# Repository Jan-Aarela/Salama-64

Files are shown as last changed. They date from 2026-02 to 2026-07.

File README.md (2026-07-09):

<!-- vim: ft=markdown nospell
-->
<i>

# Selkäsalama-64
Möykkäwaunujen proto salaman teon aikana huomasin, että salaman koko oli pikkasen pienempi mitä kuvittelin. Täysin toimiva siitähän tuli ja varsin hieno vaikka nopeasti tekasin sen.

Kaytin protoversiota yövalona kotona :D ja iski idea. Mitä jos, tästä tekisi selkäsalaman.  
[Niinkuin ysärillä...](https://github.com/Elektroniikkakerho/Archived-projects/tree/master/salama)  KiCadi tulille vaan ja lopputulos alla:

## Kuvia härpäkkeestä
|Homma in action|Etupuoli|Takapuoli| Takapuoli Kuorilla|
|---|---|---|---|
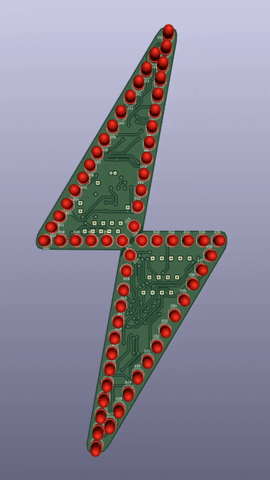
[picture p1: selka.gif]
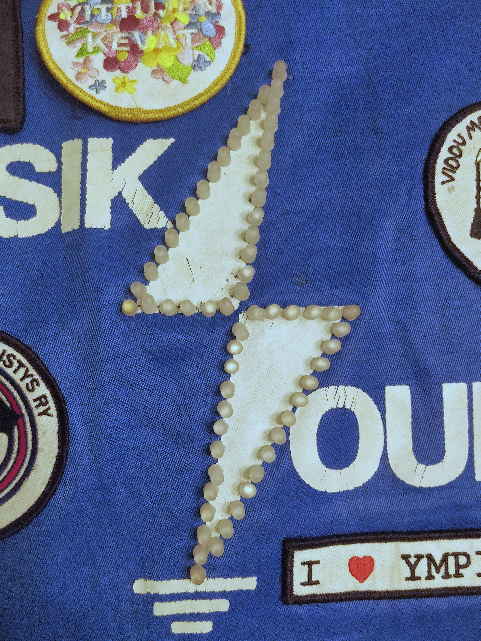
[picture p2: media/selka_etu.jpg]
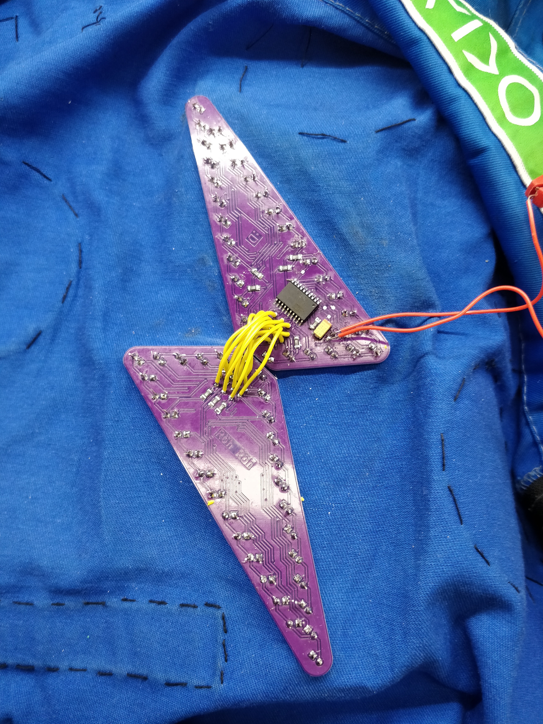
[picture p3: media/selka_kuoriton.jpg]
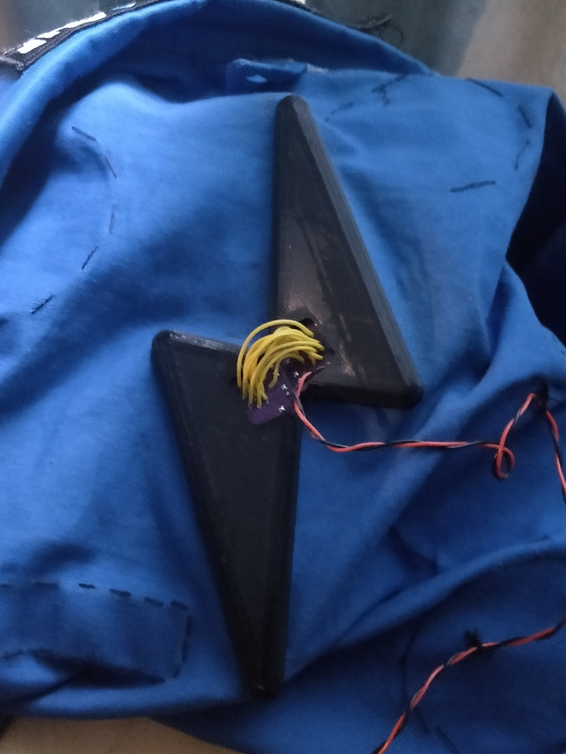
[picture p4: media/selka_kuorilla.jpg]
| | |  | 

## Skema
Homma toimii siten, että virtapankista tulee 5V ja menee suoraan piiriin. Konkka tasoittaa virran ja vastus toimii kuormana, mikäli virtapankki sammuu liian vähäistä virrankulutuksesta. Toinen ja energia tehokkaampi vaihtoehto on käyttää virtapankki kikkaa, eli ajoittain piikittää virran kulutusta ohjaamalla transistorin avulla vastusta.

Ledit on jaettu puolin kahteen eri charlieplexiin. (7^2-7 (-10) viritelmällä).  
Miksei kaikkia ledejä yhteen pleksiin? No siksi koska jos yhteen pleksiin laittaa kaikki ledit niin duty cycle olisi ~1.5%, joka on aika pieni. Kahdella pleksillä sen saa ~3%, jolloin ledit ovat kirkkaampia.

Napin tai liukukytkimen voi halutessa laittaa SW1 kohtaan johdoilla ja laittaa itse napin/liukukytkimen haalareihin, esim. kaulapantaan tai mikälie sen oikea nimi onkaan.



## Osaluettelo
| KPL | MITÄ | HUOM | 
|:---:|:--- |:--- |
|  1  | ATtiny 861A SOIC | Vähintään: Flash 4KB -  SRAM 256B |
|  64 | 5mm DIP LED | Tekijällä XL-502UBC ledit  |
|  14  | 27 Ohm 1206 | < 20ma per IO pin |
|  1  | 10 uF tant. 2312 SMD | Virtalähteen virran tasoitusta varten |
|  8  | Johdon pätkiä | Levyjen yhdistämiseen AWG 22-24 |
| 1 | Virtakaapelipari | Esim. USB |
| 1 | 6 pinninen rima | THT vaaka versio |

| Muuta?  |
|:---|
| Fläshäykseen Arduino ja 6 pinninen rima |
| PETG Filamettia kuorien tulostamiseen|
| (Optinal) Lisävastus mikäli salama sammuu|
| (Optinal) 2kpl 1206 100 nF keraamisia konkkia  |
| (Optinal) Nappi/Liukukytkin halutessa ja siihen johdot|

## Piirilevyt

Mikäli kerholla ei ole levyjä tähän projektiin, voit yrittää tehdä levyn esimerkiksi jyrsimällä tai etsaamalla. Tracien paksuudet ovat 0.4mm kestävyyden/tuotannon tolaranssin takia. Projektiin käy esimerkiksi 2-puoleinen 1oz 1.6mm PCB. Jos teet paksummasta levystä piirilevyt, joudut muokkaamaan kuorien mitat, jotta levyt mahtuvat niihin. 

Läpivientien kanssa joutuu painimaan sillä jyrsimisen/perus etsauksen jälkeen ne ei ilmesty itsestään vaan ne joutuu manuaalisesti tehdä ne. Yks tapa on käyttää läpivientiniittejä ja pressiä. Pressin jälkeen kannattaa ehdottamasti juottaa niitit traceihin, että varmasti toimivat. Jos niitit eivät mahdu reikiin, täytyy vaihtaa vioiden ja ledien reikien koot kicadillä. Tarkista, että niittien läpi mahtuu komponentit. Voi olla, että reikiä pitää kasvattaa...

## LEDIT
Tähän kannatta käyttää hyvin kirkkaita ledejä esim.  10000 mcd tai kirkkaammat,   
koska yhden ledin duty cycle on sen 1/32 ajasta eli ~ 3%.

Testaa ledin kirkkaus virtalähteellä.
Asetukset: square, 2.5V offset, 2.5V amplitude ja 3% duty cycle.

**Jos ledejä ei ole diffusoitu, niin ehdottamasti diffusoi ne.**  
Muuten selkäsalamasta tulee saatananmoinen valokeila ja sivusta katsottuna näyttää himmeältä.  

Hidas, mutta puhtaamman jäljen saat kun hiot jokaisen ledin 400-600 grid vesihiomapaperilla.

Toinen ja huomattavasti nopeampi tapa on käyttää hiekkapuhallinta. 
Eli laita kaikki ledit reikälevyyn ja teippaa ledien jalat.
Samaan tyliin kuin konkat tulee rullana. Ja ei muutakun hiekkapuhaltimella ammuskelemaan.
Voit puhdistaa ledit hiekasta laittamalla ledit astiaan jossa on nestettä (vesi/ipa) ja astian ultraäänipuhdistimeen.

## Kasausohjeet
Projekti aika pitkälti noudattaa possusalaman ohjeita.

 1. Juota siis piiri, konkka, 14 vastusta ja piikkirima.  
    Piikkirimasta trimmataan 4 sisimmäistä jalkaa, että se asettuisi lättänä.

2. Seuraavaksi laitetaan piirilevyt kiinni haalareihin.  
    Katko ledien jalat teräviksi ja yritä kohdistaa levy paikalleen.  
    Tässä kannattaa laittaa ledit niin, että haalarin salaman ääriviivat kulkee ledien keskellä.  
    Ledit mahdollisman hyvin kiinni piirilevyä vasten, näyttää suoremmalta.  
    Ja kannattaa jättää pieni rako piirilevyjen välille,  ettei hankaudu.  
    Tee sama toiselle piirilevylle. 

3. Sitten voit juottaa hyppyjohdot levylle, jossa on piiri.  
    Kannattaa juottaa hyvin ja niin että johdon muovi on mahdollisimman lähellä levyä.  
    Katko juottamisen jälkeen etupuolelta töpröttävät johdot pätkät.

4. Sittenkun kummatkin levyt ovat haalareissa kiinni, yhdistä levyt hyppykaapelilla.  
    Kaapelit menee järjestyksessä. Kanattaa olla vähän löysää, että koko härpäke pystyy taittumaan.

5. Kiinnitä Ardu piikkirimaan kiinni ja siirrä koodi levylle käyttäen AVR-ISP.  
    Ohjeet alempana.

6.  Jos kaikki toimii, juota seuraavaksi virtakaapeli ja tarvittaessa kuormavastus mikäli virtapankki lopettaa virranannon (virtasyöppö esto). Esim. 110 Ohm tai 169 Ohm...

7. Kuoret saa tulostettua FabLabilla ja mielellään kannattaa käyttää PETG. Tämä taipuu hyvin eikä halkea yhtä herkästi verrattuna esim. ABS muoviin. Tulostuksen jälkeen pitää putsata kuorien klipsien/kielien supportit pois. Esim varovasti veitsellä. Voit testata, että mahtuuko levy siihen, jos laitat 1.6mm levyn pätkän klipsin ja reunan (jossa piirilevyt istuu) väliin.

    Jos olet tehnyt piirilevyt paksummasta levystä, pitää muokata kuorien mittoja joko muokkaamalla STL tai blender projekti tiedostoa. 

8. Kuoret sopivat kummallekin piirilevylle.  
    Kolvilla voit tehdä master levyn kuoren reunalle reiän virtakaapelille.

    Kannattaa laittaa kuoret kiinni siten, että laitat ensin terävän kulman ensin kiinni ja siitä sitten siirry ylöspäin. Venytä kuorta ulospäin paina kiinni.

    Juuh, eikait siinä. Nyt **JÖÖTI** "possu" selässä  👌

## Koodi

```bash
# Siirry koodi kansioon
cd src/

# Koodin kääntäminen
avr-gcc -mmcu=attiny861 main.c kuviot.c vilkutus_charlie.c -I./ -Os -ffunction-sections -fdata-sections -Wl,--gc-sections -DF_CPU=8000000U

# Fuse asetukset
avrdude -c avrisp -p t861 -P /dev/ttyUSB0 -b 19200 -U lfuse:w:0xe2:m -U hfuse:w:0xdf:m

# Koodin siirto levylle
avrdude -c avrisp -p t861 -P /dev/ttyUSB0 -b 19200 -U flash:w:a.out

# Testaukseen voit käyttää yhtä komento riviä yhdistämällä koodin käännös ja siirto komennot (bash:)
avr-gcc -mmcu=attiny861 main.c kuviot.c vilkutus_charlie.c -I./ -Os -ffunction-sections -fdata-sections -Wl,--gc-sections -DF_CPU=8000000U && sudo avrdude -c avrisp -p t861 -P /dev/ttyUSB0 -b 19200 -U flash:w:a.out
```

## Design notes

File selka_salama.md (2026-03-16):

<!-- vim: ft=markdown nospell
-->
<i>

# Selkäsalama-64
Möykkäwaunujen proto salaman teon aikana huomasin, että salaman koko oli pikkasen pienempi mitä kuvittelin. Täysin toimiva siitähän tuli ja varsin hieno vaikka nopeasti tekasin sen.

Ihailin sitä tunteja ja mieleeni tuli yhtäkkiä idea. Mitä jos, tästä tekisi selkäsalaman. [Niinkuin ysärillä...](https://github.com/Elektroniikkakerho/Archived-projects/tree/master/salama)  
KiCadi tulille vaan ja lopputulos alla:

## Kuvia härpäkkeestä
|Demo|Etupuoli|Takapuoli Kuoriton| Takapuoli Kuorilla|
|---|---|---|---|
| | |  | 

## Skema
Koska selkäsalama koostuu kahdesta eri piirilevystä, skemaan on lisätty hyppykaapelit, jotka yhdistävät ledien multiplexauksen. esim. J13 --> J14.

Koska levy on niin täynnä traceja, enkä jaksunut vaivata, varsinaista piikkirimaa ohjelmoinille en laittanut. Levyssä on 4 pientä testi pädiä (lähellä piiriä), joihin juotetaan ohjelmointi kaapelit (RESET, SCK, MOSI JA MISO). Ohjelmoinnin aikana, voit käyttää kuormavastuksen pädejä (GND ja 5V).

Skemassa on cyaanin värisiä viivoja, jotka tarkoittavan piirin olevan alemmassa piirilevyssä.



## Osaluettelo
| KPL | MITÄ | HUOM | 
|:---:|:--- |:--- |
|  1  | ATtiny 861A SOIC | **U/SU** malli ainakin toimii  |
|  64 | 5mm DIP LED | Tekijällä XL-502UBC ledit  |
|  8  | 110Ohm 1206 | < 20ma per IO pin |
|  1  | 10uF tant. SMD | Virtalähteen virran tasoitusta varten |

| Muuta?  |
|:---|
| Joku kaapeli virransyöttä varten |
| Fläshäykseen Arduino ja 6 pinninen rima |
| Johdon pätkiä levyjen yhdistämiseen |
| PETG Filamettia kuorien tulostamiseen|
| Lisävastus mikäli salama sammuu|

## Piirilevyt
Mikäli kerholla ei ole levyjä tähän projektiin, voit yrittää tehdä levyn esimerkiksi jyrsimällä tai etsaamalla. Tracien paksuudet ovat 0.4mm kestävyyden/tuotannon tolaranssin takia. Projektiin käy esimerkiksi 2-puoleinen 1oz 1.6mm PCB. Jos teet paksummasta levystä piirilevyt, joudut muokkaamaan kuorien mitat, jotta levyt mahtuvat niihin. 

Läpivientien kanssa joutuu painimaan sillä jyrsimisen/etsauksen jälkeen ne ei ilmesty itsestään vaan ne joutuu manuaalisesti tehdä ne. Yks tapa on käyttää läpivientiniittejä ja pressiä. Pressin jälkeen kannattaa ehdottamasti juottaa niitit traceihin, että varmasti toimivat. Jos niitit eivät mahdu reikiin, täytyy vaihtaa vioiden ja ledien reikien koot kicadillä. 

## LEDIT
Tähän kannatta käyttää hyvin kirkkaita ledejä ~ 10000 mcd, sillä yhden ledin duty cycle on sen 1/64 ajasta eli ~ 1.5%. Tai tuplasti riippuen mitä koodin hedari tiedostoa käytät.

Testaa diffusoitu ledi virtalähteellä.  
Asetukset: square, 1.6V offset, 3.2V amplitude ja 1.5% tai 3% duty cycle.

Jos omasta mielestä sopivan kirkkaat ledit, ei muutakun kasamaan...

## Kasausohjeet
Projekti aika pitkälti noudattaa possusalaman ohjeita.

 1. Juota siis piiri, konkka ja 8 vastusta. Jätä konkan vierestä vastus juottamatta.  
    Se on kuormavastukselle varattu paikka ja käytetään myös ohjelmoinnissa.

2. Sitten voit juottaa hyppyjohdot levylle, jossa on piiri.  
    Kannattaa juottaa hyvin ja niin että johdon muovi on mahdollisimman lähellä levyä.  
    Katko juottamisen jälkeen etupuolelta töpröttävät johdot pätkät.

3. Seuraavaksi laitetaan piirilevyt kiinni haalareihin.  
    Katko ledien jalat teräviksi ja yritä kohdistaa levy paikalleen.  
    Tässä kannattaa laittaa ledit niin, että haalarin salaman ääriviivat kulkee ledien keskellä.  
    Suosittelen laittamaan ledit mahdollisman hyvin kiinni piirilevyä vasten, näyttää suoremmalta.  
    Ja kannattaa jättää pieni rako piirilevyjen välille,  ettei hankaudu.  
    Tee sama toiselle piirilevylle. 

    **Jos ledejä ei ole diffusoitu, niin ehdottamasti diffusoi ne.**  
    Muuten selkäsalamasta tulee saatananmoinen valokeila ja sivusta katsottuna näyttää himmeältä.  

    Hidas, mutta puhtaamman jäljen saat kun hiot jokaisen ledin 400-600 grid vesihiomapaperilla.  
    Toinen ja huomattavasti nopeampi tapa on käyttää hiekkapuhallinta. 
    Eli laita kaikki ledit reikälevyyn ja teippaa ledien jalat.
    Samaan tyliin kuin vastukset tulee rullana. Ja ei muutakun hiekkapuhaltimella ammuskelemaan.

4. Sittenkun kummatkin levyt ovat haalareissa kiinni, yhdistä levyt hyppykaapelilla.  
    Katso leiskasta, mikä kaapeli menee mihinkin, mutta kannattaa aloittaa yhtistäminen ylhäältä alas, vasemmalta oikealle, järjestyksessa. Tuplachekkaa leiskasta/skemasta, että kaikki menee oikein. Kaapeleiden ei kannata olla kovin pitkiä eikä lyhyitä.

5. Tee arduun yhteys. Tässä kuva missä ovat selkäsalaman ohjelmointi pädit:
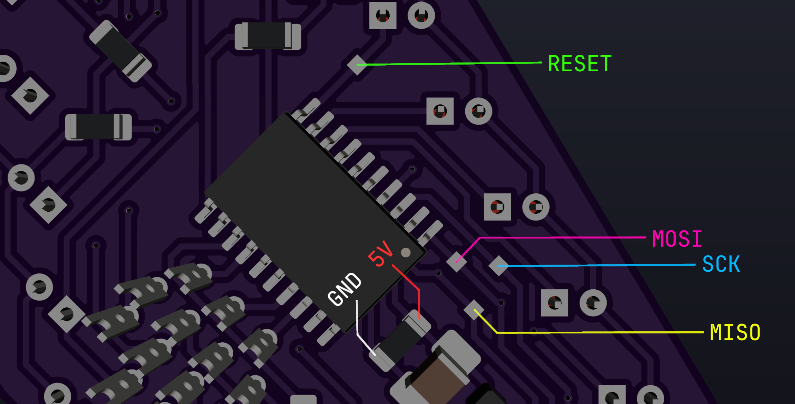
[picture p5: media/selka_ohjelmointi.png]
    

6. **Seuraavaksi siirrä koodi levylle ja palaa tähän takaisin.**

7.  Jos kaikki toimii, juota seuraavaksi virtakaapeli ja tarvittaessa kuormavastus mikäli virtapankki lopettaa virranannon (virtasyöppö esto). Esim. 110Ohm tai 169Ohm...

8. Kuoret saa tulostettua FabLabilla ja mielellään kannattaa käyttää PETG. Tämä taipuu hyvin eikä halkea yhtä herkästi verrattuna esim. ABS muoviin. Tulostuksen jälkeen pitää putsata kuorien klipsien/kielien supportit pois. Esim varovasti veitsellä. Voit testata, että mahtuuko levy siihen, jos laitat 1.6mm 1oz/2oz levyn pätkän klipsin ja reunan (jossa piirilevyt istuu) väliin.

    Jos olet tehnyt piirilevyt paksummasta levystä, täytyy sinun muokata kuorien mittoja joko muokkaamalla STL tai blender projekti tiedostoa. 

9. Kuoret sopivat kummallekin piirilevylle.  
Kannattaa laittaa kuoret kiinni siten, että laitat ensin terävän kulman ensin kiinni ja siitä sitten siirry ylöspäin. Venytä kuorta ulospäin paina kiinni.

Juuh, eikait siinä. Nyt loistaa **MEGA**possu selässä  👌

## Koodi

```bash
# Siirry koodi kansioon
cd src/

# Koodin kääntäminen
avr-gcc -mmcu=attiny861 main.c -I./ -Os -ffunction-sections -fdata-sections -Wl,--gc-sections -DF_CPU=8000000U

# Fuse asetukset mm. efektien testaukseen... (huom. 8 lediä ei toimi)
avrdude -c avrisp -p t861 -P /dev/ttyUSB0 -b 19200 -U lfuse:w:0xe2:m -U hfuse:w:0xdf:m

# Koodin siirto levylle
avrdude -c avrisp -p t861 -P /dev/ttyUSB0 -b 19200 -U flash:w:a.out

# kuviot.c tiedossa on hedari tiedostot vilkutus.c ja vilkutus_2x.c.
# Voit kokeilla vaihtaa tiedostoa.
# 2x tiedosto vilkuttaa kahta lediä samaan aikaan, eli se on kirkkaampi. 2x duty cycle.
# Mutta atm buginen, joka kahdeksas ledi himmenee/kirkastuu riippiuen kuvioefektistä.
# Voit myös muokata / tehdä omia kuvioefektejä muokkaamalla main.c ja kuviot.c

# Testaukseen voit käyttää yhtä komento riviä yhdistämällä koodin käännös ja siirto komennot.
# (bash shell)
avr-gcc -mmcu=attiny861 main.c -I./ -Os -ffunction-sections -fdata-sections -Wl,--gc-sections -DF_CPU=8000000U && sudo avrdude -c avrisp -p t861 -P /dev/ttyUSB0 -b 19200 -U flash:w:a.out

# Lopulliset fuse asetukset  (Reset pin --> IO pin) 
# Kaikki ledit toimii, mutta tämän jälkeen et pysty puskea uutta koodia!!! 
avrdude -c avrisp -p t861 -P /dev/ttyUSB0 -b 19200 -U lfuse:w:0xe2:m -U hfuse:w:0x5f:m
```

## Fuse asetuksien nollaaminen
Tyliin joku 12V high voltage fuse resetter setuppi tai laita vaan uusi pirii tilalle :D

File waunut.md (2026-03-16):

<!-- vim: ft=markdown nospell
-->
<i>

# Waunujen salama
Koko git repon alkuperäinen tarkoitus oli tehdä möykkäwaunuihin **MEGA** salama waunujen keulaan.
Mutta pitihän siinä välissä tehdä selkasalama sidequest ja nyt palataan alkuperäiseen projektiin.

## Skema
Sama mitä proto versiossa, mutta lisätty NPN transistorit jokaisen multipleksaus sarakkeen jälkeen.  
Proto versiossa ilmeni, että kun vilkutat yhtä lediä 64-ledi multiplex setupissa, kirkkaus tippuu rajusti. Selkäsalamaan lisäsin hedari tiedoston joka vilkuttaa kahta lediä kerralla. Just riittää attinyn IO virta speksin mukaan. (40mA MAX per IO pin, eli 2x~17mA = 34mA). 

Tässä versiossa 8 lediä vilkuttaa kerralla, joten se ylittää sen 40mA ( ~160mA) ja lopputulos olisi "magick smoke"... Eli pelkkä koodin muutos tähän hommaan ei riitä.

Nyt multipleksauksen "blocking" sarakeet ovat attinyn IO ohjaamia transistorin kautta, joka sitten ulostaa loput virrat maahan.



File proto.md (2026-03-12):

<!-- vim: ft=markdown nospell
-->
<i>

# Salama-64

Vanha tuttu [possusalaman ](https://github.com/Elektroniikkakerho/Led-merkki/tree/master) skema, paitsi tässä tuplasti ledejä 8x8 multiplex setupilla.  
Fuse asetus ajaa RESET pinnin IO pinniksi, jonka jälkeen koodin uudelleen puskeminen ei enään onnistu.  



## Protolevy mk2
| Etupuoli <sub>tirsk</sub> | Takapuoli <sub>tirsk</sub> |
|:---|:--- |
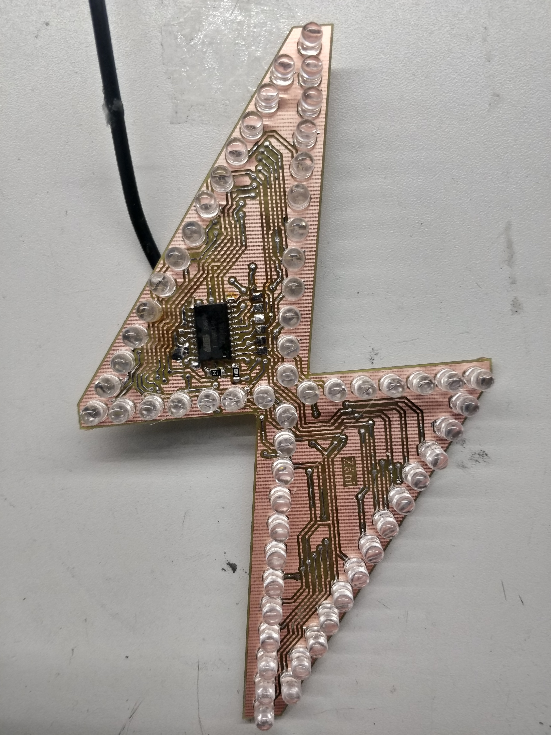
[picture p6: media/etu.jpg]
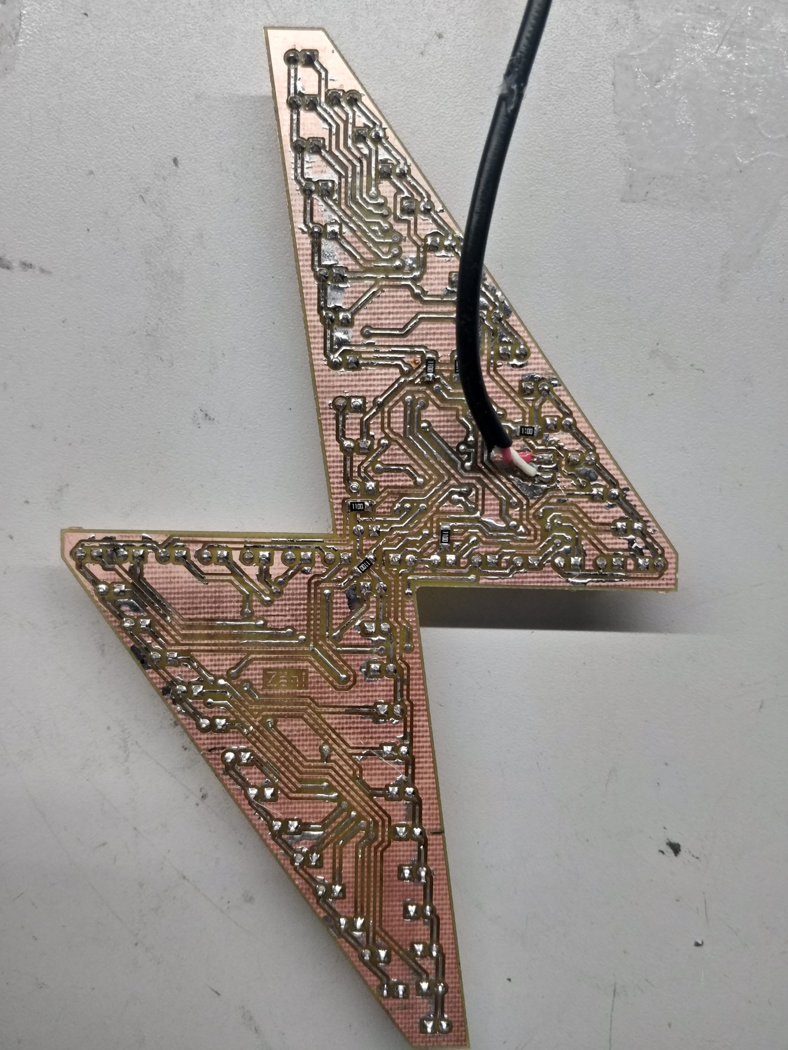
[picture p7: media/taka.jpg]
|   |  

## Demo


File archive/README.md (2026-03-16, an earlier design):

<!-- vim: ft=markdown nospell
-->
<i>

# Koska aina voi olla enemmän salamia</b>

| Protolevy mk2 | [Selkäsalama](https://github.com/Elektroniikkakerho/Archived-projects/tree/master/salama ) Remake | Möykkäwaunujen Salama WIP
|:---:|:---:|:---:|
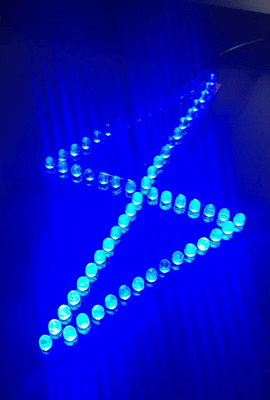
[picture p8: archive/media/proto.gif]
|   |  | 
| [Deets](proto.md) | [Deets](selka_salama.md)| [Deets](waunut.md)|

<!-- <img src="proto.gif" alt="alt" width="50%"> -->

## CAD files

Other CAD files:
blender_selka/kuoret.blend

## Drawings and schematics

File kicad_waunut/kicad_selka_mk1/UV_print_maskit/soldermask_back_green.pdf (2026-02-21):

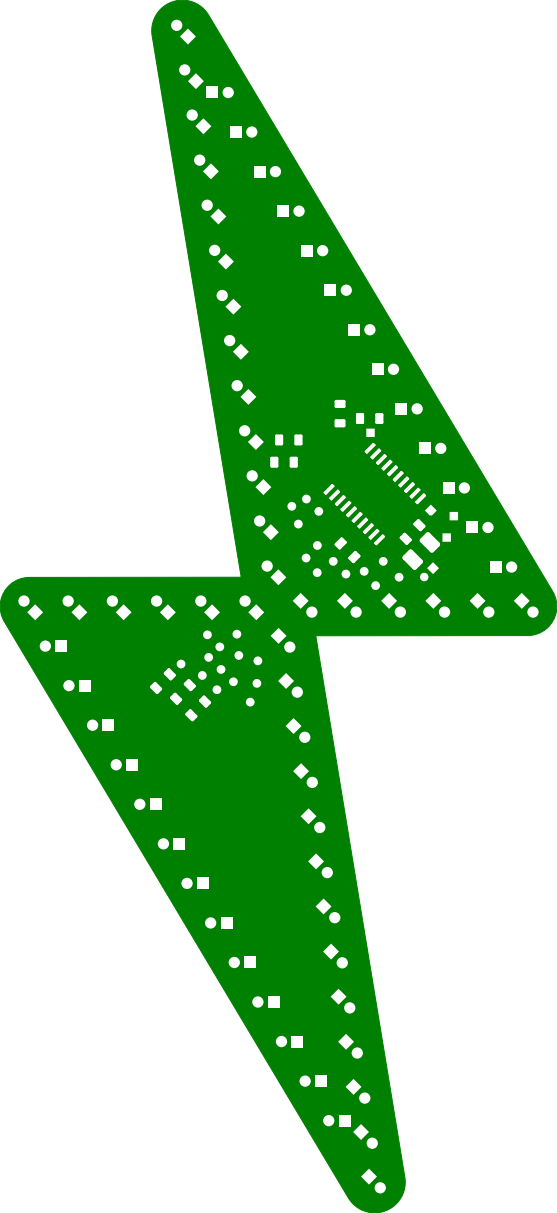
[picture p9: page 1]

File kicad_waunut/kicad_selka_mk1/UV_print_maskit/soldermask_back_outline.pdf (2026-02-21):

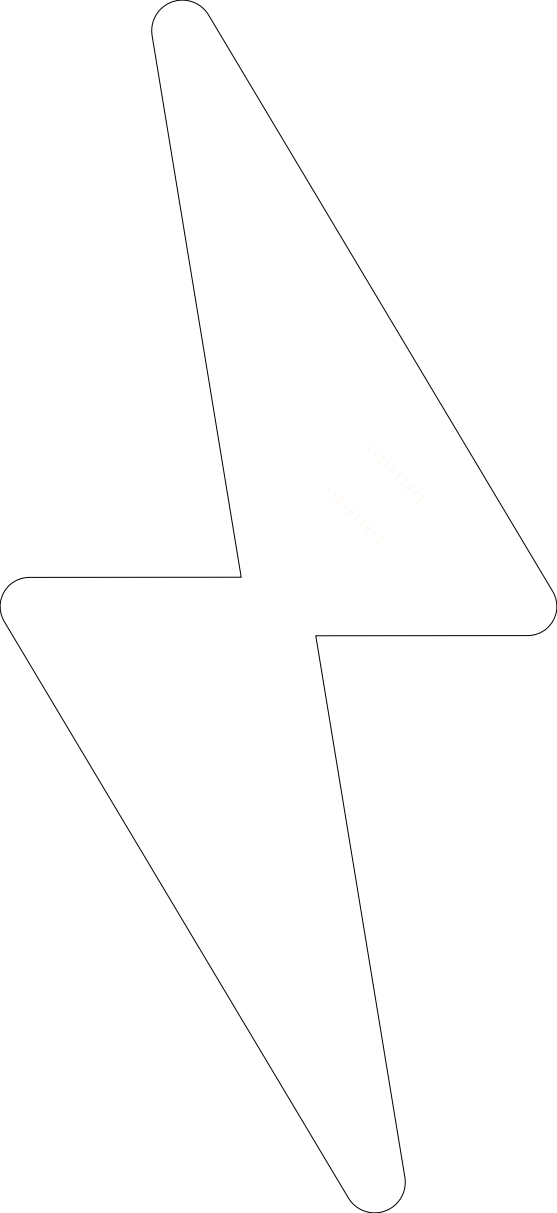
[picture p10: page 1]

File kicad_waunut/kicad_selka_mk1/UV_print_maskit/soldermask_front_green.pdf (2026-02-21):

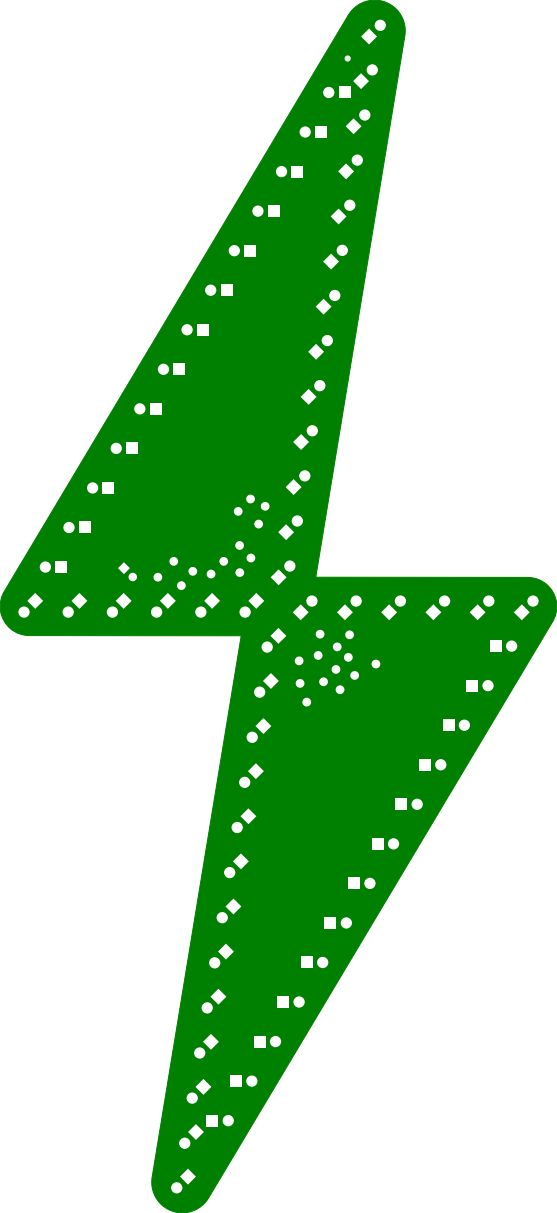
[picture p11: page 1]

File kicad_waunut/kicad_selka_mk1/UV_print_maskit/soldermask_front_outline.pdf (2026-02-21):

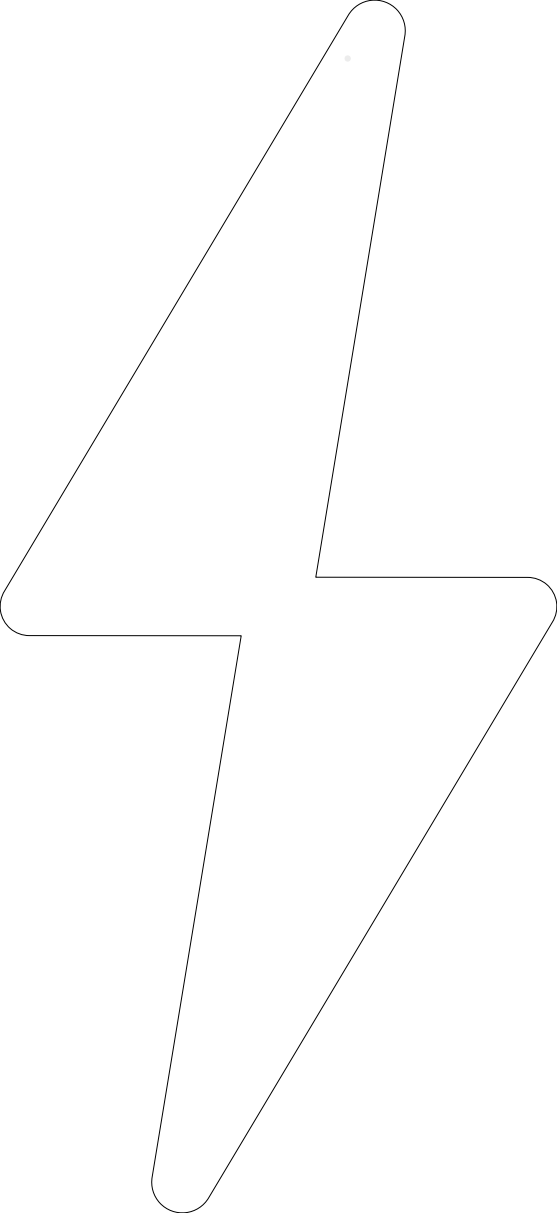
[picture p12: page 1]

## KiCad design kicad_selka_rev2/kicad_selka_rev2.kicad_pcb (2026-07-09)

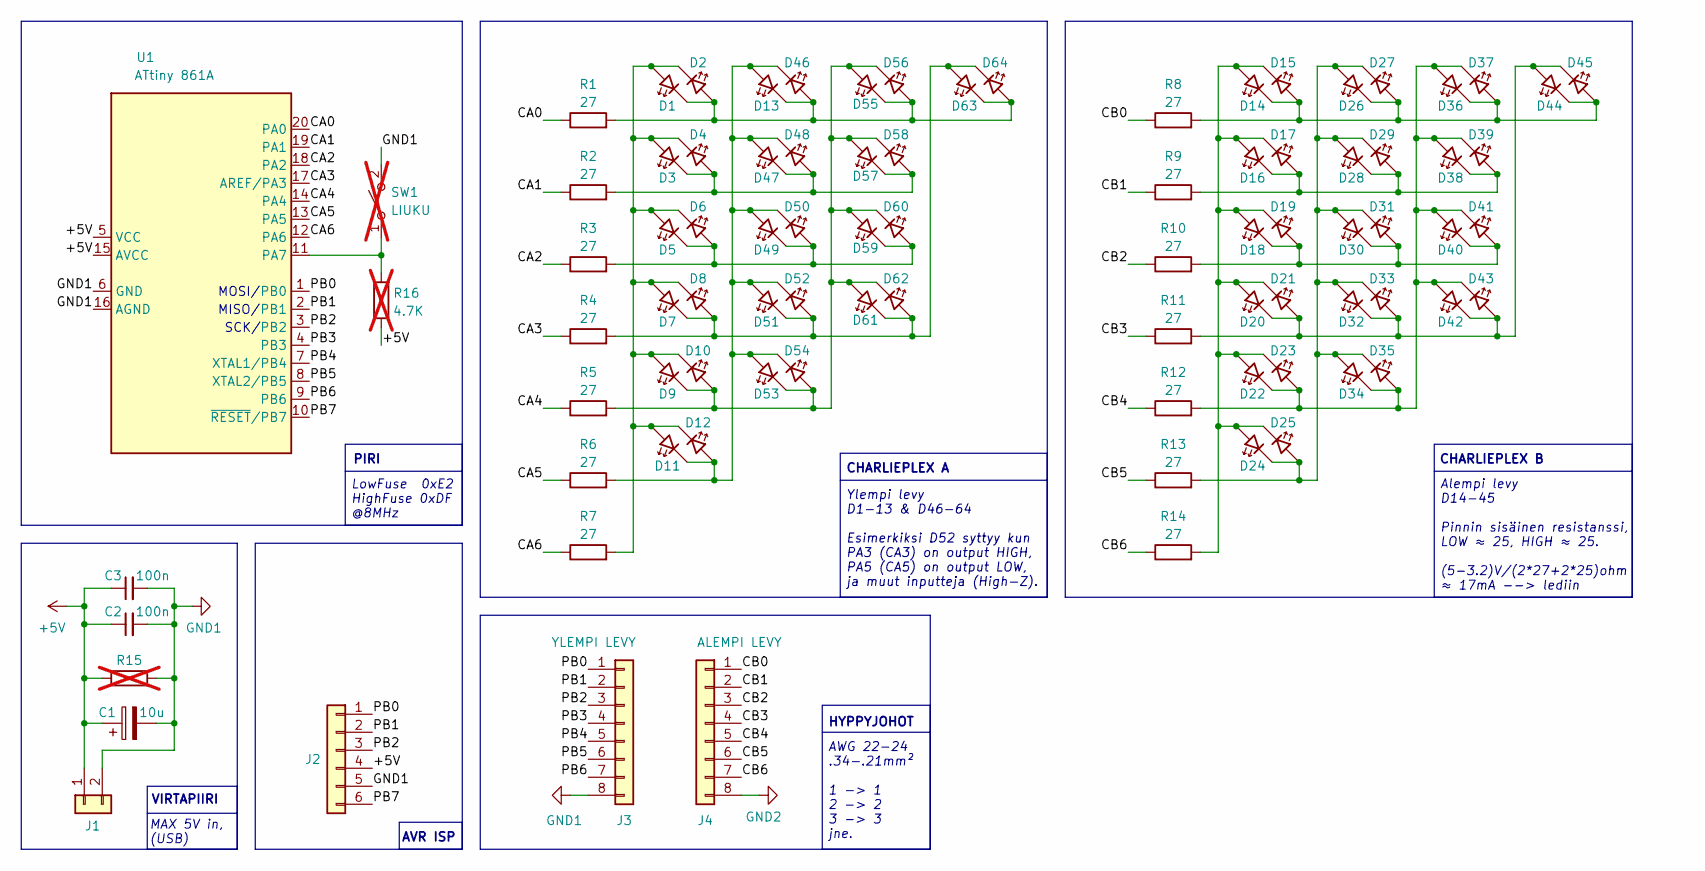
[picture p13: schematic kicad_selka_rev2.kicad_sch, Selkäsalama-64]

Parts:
C1: 10u; CP_EIA-6032-28_Kemet-C_HandSolder
C2, C3: 100n; C_1206_3216Metric_Pad1.33x1.80mm_HandSolder
D1, D2, D3, D4, D5, D6, D7, D8, D9, D10, D11, D12, D13, D14, D15, D16, D17, D18, D19, D20, D21, D22, D23, D24, D25, D26, D27, D28, D29, D30, D31, D32, D33, D34, D35, D36, D37, D38, D39, D40, D41, D42, D43, D44, D45, D46, D47, D48, D49, D50, D51, D52, D53, D54, D55, D56, D57, D58, D59, D60, D61, D62, D63, D64: LED_45deg; LED_D5.0mm_blue_zani
J1: Conn_01x02; PinHeader_1x02_P2.54mm_Vertical
J2: Conn_01x06; PinHeader_1x06_P2.54mm_Horizontal_smd_tht
J3, J4: Conn_01x08; PinHeader_1x08_P2.00mm_Vertical_levee
R1, R2, R3, R4, R5, R6, R7, R8, R9, R10, R11, R12, R13, R14: 27; R_1206_3216Metric_Pad1.30x1.75mm_HandSolder
R15: X; R_1210_3225Metric_Pad1.30x2.65mm_HandSolder; not fitted
R16: 4.7K; R_0805_2012Metric_Pad1.20x1.40mm_HandSolder; not fitted
SW1: LIUKU; PinHeader_1x02_P2.54mm_Vertical; not fitted
U1: ATtiny 861A; SOIC-20W_7.5x12.8mm_P1.27mm

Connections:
+5V: C1.1, C2.1, C3.1, J1.1, J2.4, R15.1, R16.1, U1.5 (VCC), U1.15 (AVCC)
/CA0: R1.1, U1.20 (PA0)
/CA1: R2.1, U1.19 (PA1)
/CA2: R3.1, U1.18 (PA2)
/CA3: R4.1, U1.17 (AREF/PA3)
/CA4: R5.1, U1.14 (PA4)
/CA5: R6.1, U1.13 (PA5)
/CA6: R7.1, U1.12 (PA6)
/CB0: J4.1, R8.1
/CB1: J4.2, R9.1
/CB2: J4.3, R10.1
/CB3: J4.4, R11.1
/CB4: J4.5, R12.1
/CB5: J4.6, R13.1
/CB6: J4.7, R14.1
/PB0: J2.1, J3.1, U1.1 (PB0)
/PB1: J2.2, J3.2, U1.2 (PB1)
/PB2: J2.3, J3.3, U1.3 (PB2)
/PB3: J3.4, U1.4 (PB3)
/PB4: J3.5, U1.7 (XTAL1/PB4)
/PB5: J3.6, U1.8 (XTAL2/PB5)
/PB6: J3.7, U1.9 (PB6)
/PB7: J2.6, U1.10 (~RESET/PB7)
GND1: C1.2, C2.2, C3.2, J1.2, J2.5, J3.8, R15.2, SW1.2 (B), U1.6 (GND), U1.16 (AGND)
GND2: J4.8
unnamed: D1.2 (A), D2.1 (K), D3.2 (A), D4.1 (K), D5.2 (A), D6.1 (K), D7.2 (A), D8.1 (K), D9.2 (A), D10.1 (K), D11.2 (A), D12.1 (K), R7.2
unnamed: D1.1 (K), D2.2 (A), D13.1 (K), D46.2 (A), D55.1 (K), D56.2 (A), D63.1 (K), D64.2 (A), R1.2
unnamed: D3.1 (K), D4.2 (A), D47.1 (K), D48.2 (A), D57.1 (K), D58.2 (A), R2.2
unnamed: D9.1 (K), D10.2 (A), D53.1 (K), D54.2 (A), D55.2 (A), D56.1 (K), D57.2 (A), D58.1 (K), D59.2 (A), D60.1 (K), D61.2 (A), D62.1 (K), R5.2
unnamed: D11.1 (K), D12.2 (A), D13.2 (A), D46.1 (K), D47.2 (A), D48.1 (K), D49.2 (A), D50.1 (K), D51.2 (A), D52.1 (K), D53.2 (A), D54.1 (K), R6.2
unnamed: D14.2 (A), D15.1 (K), D16.2 (A), D17.1 (K), D18.2 (A), D19.1 (K), D20.2 (A), D21.1 (K), D22.2 (A), D23.1 (K), D24.2 (A), D25.1 (K), R14.2
unnamed: D14.1 (K), D15.2 (A), D26.1 (K), D27.2 (A), D36.1 (K), D37.2 (A), D44.1 (K), D45.2 (A), R8.2
unnamed: D16.1 (K), D17.2 (A), D28.1 (K), D29.2 (A), D38.1 (K), D39.2 (A), R9.2
unnamed: D18.1 (K), D19.2 (A), D30.1 (K), D31.2 (A), D40.1 (K), D41.2 (A), R10.2
unnamed: D20.1 (K), D21.2 (A), D32.1 (K), D33.2 (A), D42.1 (K), D43.2 (A), D44.2 (A), D45.1 (K), R11.2
unnamed: D22.1 (K), D23.2 (A), D34.1 (K), D35.2 (A), D36.2 (A), D37.1 (K), D38.2 (A), D39.1 (K), D40.2 (A), D41.1 (K), D42.2 (A), D43.1 (K), R12.2
unnamed: D24.1 (K), D25.2 (A), D26.2 (A), D27.1 (K), D28.2 (A), D29.1 (K), D30.2 (A), D31.1 (K), D32.2 (A), D33.1 (K), D34.2 (A), D35.1 (K), R13.2
unnamed: D5.1 (K), D6.2 (A), D49.1 (K), D50.2 (A), D59.1 (K), D60.2 (A), R3.2
unnamed: D7.1 (K), D8.2 (A), D51.1 (K), D52.2 (A), D61.1 (K), D62.2 (A), D63.2 (A), D64.1 (K), R4.2
unnamed: R16.2, SW1.1 (A), U1.11 (PA7)

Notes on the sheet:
VIRTAPIIRI
SCK/
MISO/
MOSI/
AWG 22-24 .34-.21mm² 1 -> 1 2 -> 2 3 -> 3 jne.
CHARLIEPLEX A
CHARLIEPLEX B
MAX 5V in, (USB)
Ylempi levy D1-13 & D46-64 Esimerkiksi D52 syttyy kun PA3 (CA3) on output HIGH, PA5 (CA5) on output LOW, ja muut inputteja (High-Z).
Alempi levy D14-45 Pinnin sisäinen resistanssi, LOW ≈ 25, HIGH ≈ 25. (5-3.2)V/(2*27+2*25)ohm ≈ 17mA --> lediin
AVR ISP
PIRI
LowFuse 0xE2 HighFuse 0xDF @8MHz
HYPPYJOHOT

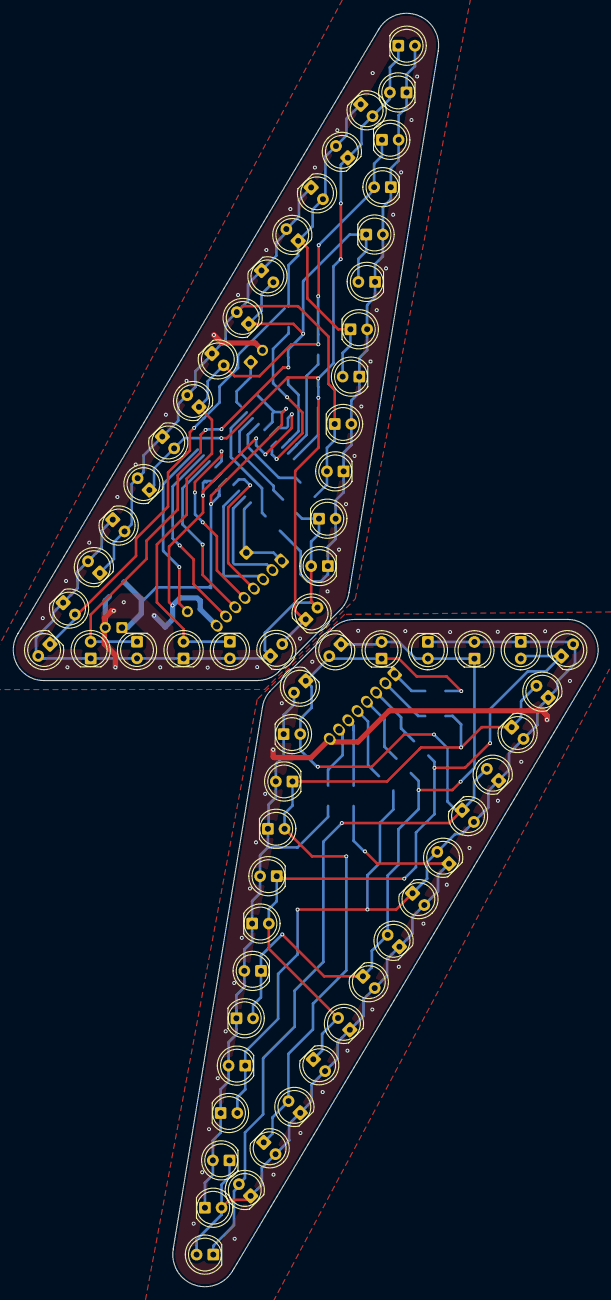
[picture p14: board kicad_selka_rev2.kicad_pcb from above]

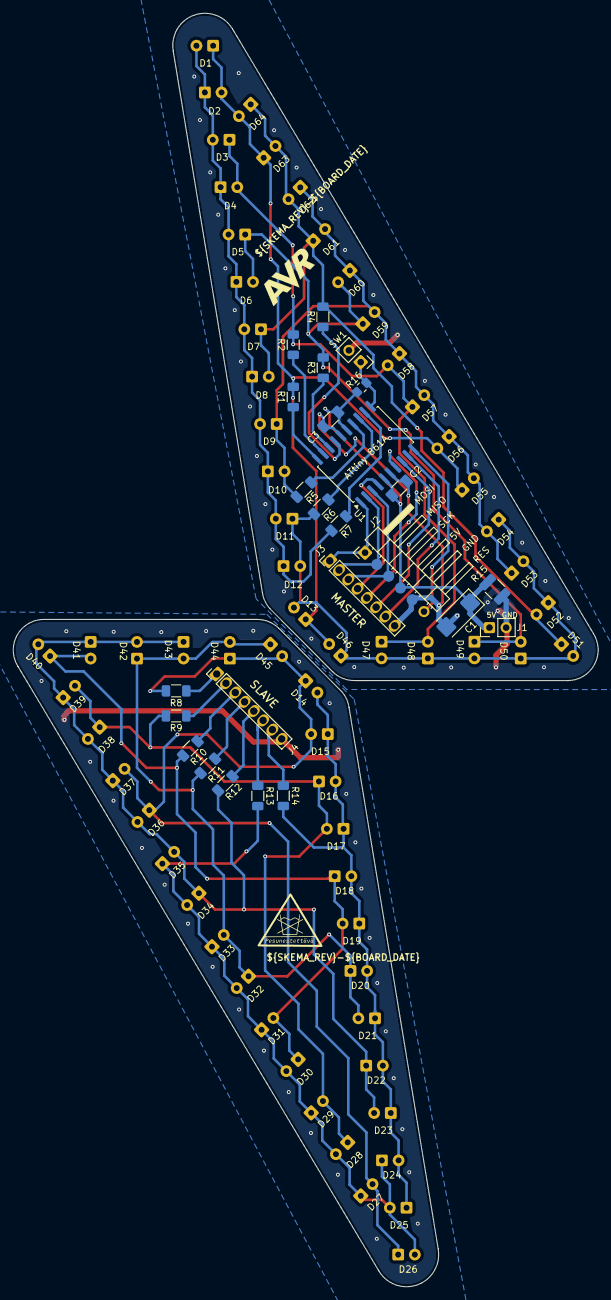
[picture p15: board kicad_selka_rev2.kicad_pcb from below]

Board: 2 copper layers, 89.2 x 194.1 mm, 89 parts (25 on the bottom side), 39 nets.

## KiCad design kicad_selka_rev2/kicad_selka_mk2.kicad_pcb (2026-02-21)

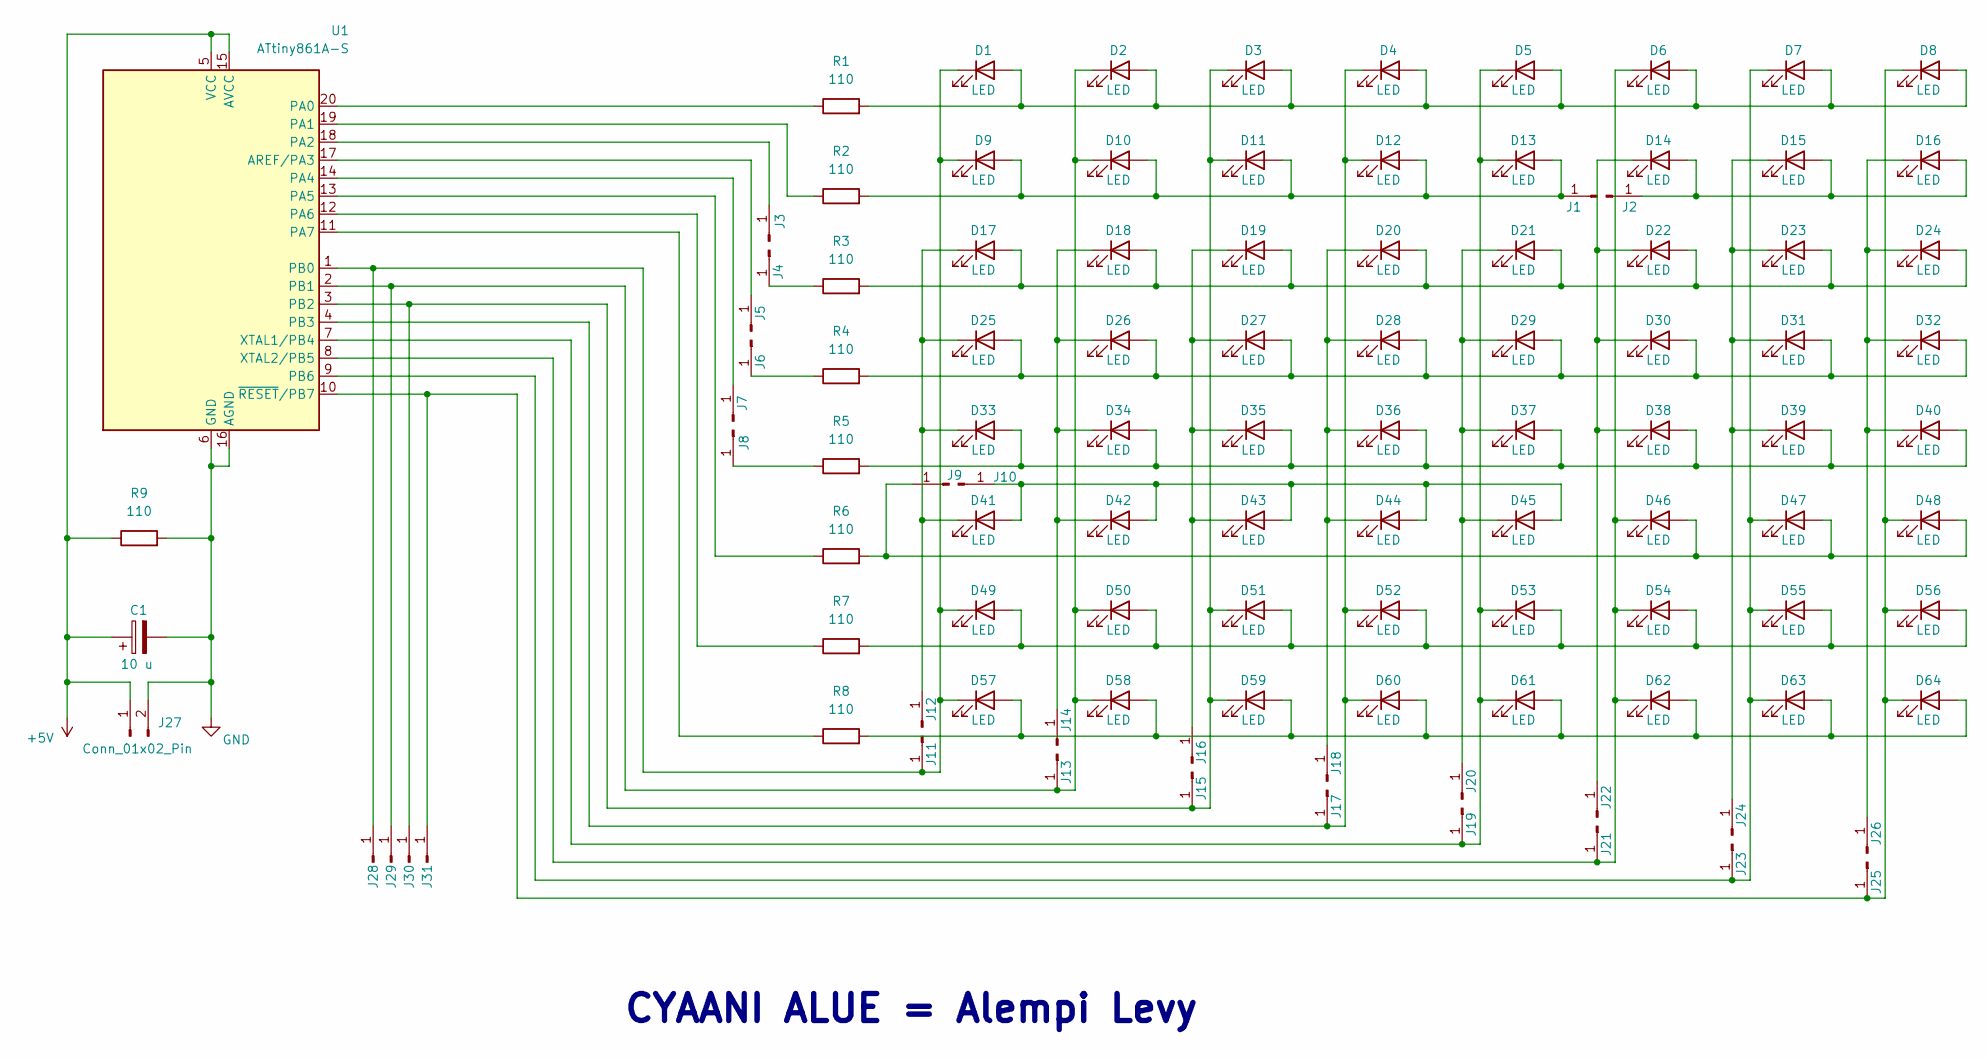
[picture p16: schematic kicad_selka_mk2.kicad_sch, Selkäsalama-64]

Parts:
C1: 10 u; C_1210_3225Metric_Pad1.33x2.70mm_HandSolder
D1, D2, D3, D4, D5, D6, D7, D8, D9, D10, D11, D12, D13, D14, D15, D16, D17, D18, D19, D20, D21, D22, D23, D24, D25, D26, D27, D28, D29, D30, D31, D32, D33, D34, D35, D36, D37, D38, D39, D40, D41, D42, D43, D44, D45, D46, D47, D48, D49, D50, D51, D52, D53, D54, D55, D56, D57, D58, D59, D60, D61, D62, D63, D64: LED; LED_D5.0mm
J1, J2, J3, J5, J6, J7, J8, J9, J10, J11, J12, J13, J14, J15, J16, J17, J18, J19, J20, J21, J22, J23, J24, J25, J26: Conn_01x01_Pin; PinSocket_1x01_P2.54mm_Vertical
J4: Conn_01x01_Pin; Pin_D0.7mm_L6.5mm_W1.8mm_FlatFork
J27: Conn_01x02_Pin; PinHeader_1x02_P2.00mm_Vertical
J28, J29, J30, J31: Conn_01x01_Pin; TestPoint_Pad_1.0x1.0mm
R1, R2, R3, R4, R5, R6, R7, R8, R9: 110; R_1206_3216Metric_Pad1.30x1.75mm_HandSolder
U1: ATtiny861A-S; SOIC-20W_7.5x12.8mm_P1.27mm

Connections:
+5V: C1.1, J27.1, R9.1, U1.5 (VCC), U1.15 (AVCC)
GND: C1.2, J27.2, R9.2, U1.6 (GND), U1.16 (AGND)
unnamed: D1.2 (A), D2.2 (A), D3.2 (A), D4.2 (A), D5.2 (A), D6.2 (A), D7.2 (A), D8.2 (A), R1.2
unnamed: D1.1 (K), D9.1 (K), D49.1 (K), D57.1 (K), J11.1, J28.1, U1.1 (PB0)
unnamed: D9.2 (A), D10.2 (A), D11.2 (A), D12.2 (A), D13.2 (A), J1.1, R2.2
unnamed: D2.1 (K), D10.1 (K), D50.1 (K), D58.1 (K), J13.1, J29.1, U1.2 (PB1)
unnamed: D3.1 (K), D11.1 (K), D51.1 (K), D59.1 (K), J15.1, J30.1, U1.3 (PB2)
unnamed: D4.1 (K), D12.1 (K), D52.1 (K), D60.1 (K), J17.1, U1.4 (PB3)
unnamed: D5.1 (K), D13.1 (K), D53.1 (K), D61.1 (K), J19.1, U1.7 (XTAL1/PB4)
unnamed: D14.2 (A), D15.2 (A), D16.2 (A), J2.1
unnamed: D14.1 (K), D22.1 (K), D30.1 (K), D38.1 (K), J22.1
unnamed: D15.1 (K), D23.1 (K), D31.1 (K), D39.1 (K), J24.1
unnamed: D16.1 (K), D24.1 (K), D32.1 (K), D40.1 (K), J26.1
unnamed: D17.2 (A), D18.2 (A), D19.2 (A), D20.2 (A), D21.2 (A), D22.2 (A), D23.2 (A), D24.2 (A), R3.2
unnamed: D17.1 (K), D25.1 (K), D33.1 (K), D41.1 (K), J12.1
unnamed: D18.1 (K), D26.1 (K), D34.1 (K), D42.1 (K), J14.1
unnamed: D19.1 (K), D27.1 (K), D35.1 (K), D43.1 (K), J16.1
unnamed: D20.1 (K), D28.1 (K), D36.1 (K), D44.1 (K), J18.1
unnamed: D21.1 (K), D29.1 (K), D37.1 (K), D45.1 (K), J20.1
unnamed: D25.2 (A), D26.2 (A), D27.2 (A), D28.2 (A), D29.2 (A), D30.2 (A), D31.2 (A), D32.2 (A), R4.2
unnamed: D33.2 (A), D34.2 (A), D35.2 (A), D36.2 (A), D37.2 (A), D38.2 (A), D39.2 (A), D40.2 (A), R5.2
unnamed: D41.2 (A), D42.2 (A), D43.2 (A), D44.2 (A), D45.2 (A), J10.1
unnamed: D46.2 (A), D47.2 (A), D48.2 (A), J9.1, R6.2
unnamed: D6.1 (K), D46.1 (K), D54.1 (K), D62.1 (K), J21.1, U1.8 (XTAL2/PB5)
unnamed: D7.1 (K), D47.1 (K), D55.1 (K), D63.1 (K), J23.1, U1.9 (PB6)
unnamed: D8.1 (K), D48.1 (K), D56.1 (K), D64.1 (K), J25.1, J31.1, U1.10 (~RESET/PB7)
unnamed: D49.2 (A), D50.2 (A), D51.2 (A), D52.2 (A), D53.2 (A), D54.2 (A), D55.2 (A), D56.2 (A), R7.2
unnamed: D57.2 (A), D58.2 (A), D59.2 (A), D60.2 (A), D61.2 (A), D62.2 (A), D63.2 (A), D64.2 (A), R8.2
unnamed: J3.1, U1.18 (PA2)
unnamed: J4.1, R3.1
unnamed: J5.1, U1.17 (AREF/PA3)
unnamed: J6.1, R4.1
unnamed: J7.1, U1.14 (PA4)
unnamed: J8.1, R5.1
unnamed: R1.1, U1.20 (PA0)
unnamed: R2.1, U1.19 (PA1)
unnamed: R6.1, U1.13 (PA5)
unnamed: R7.1, U1.12 (PA6)
unnamed: R8.1, U1.11 (PA7)

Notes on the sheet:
CYAANI ALUE = Alempi Levy

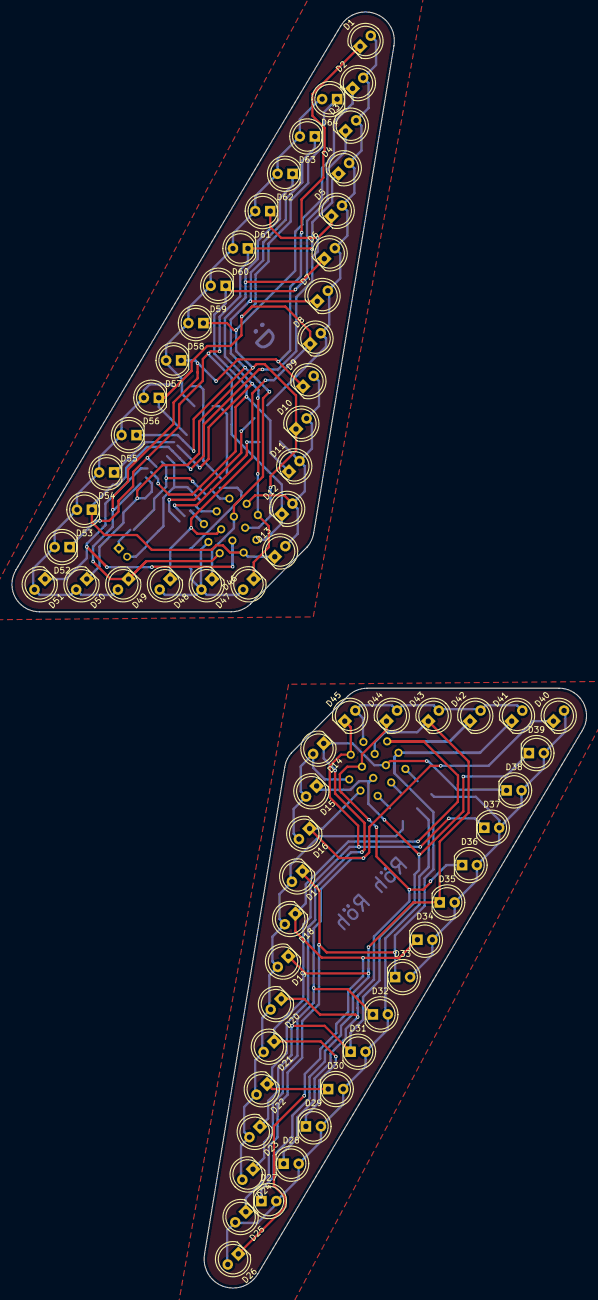
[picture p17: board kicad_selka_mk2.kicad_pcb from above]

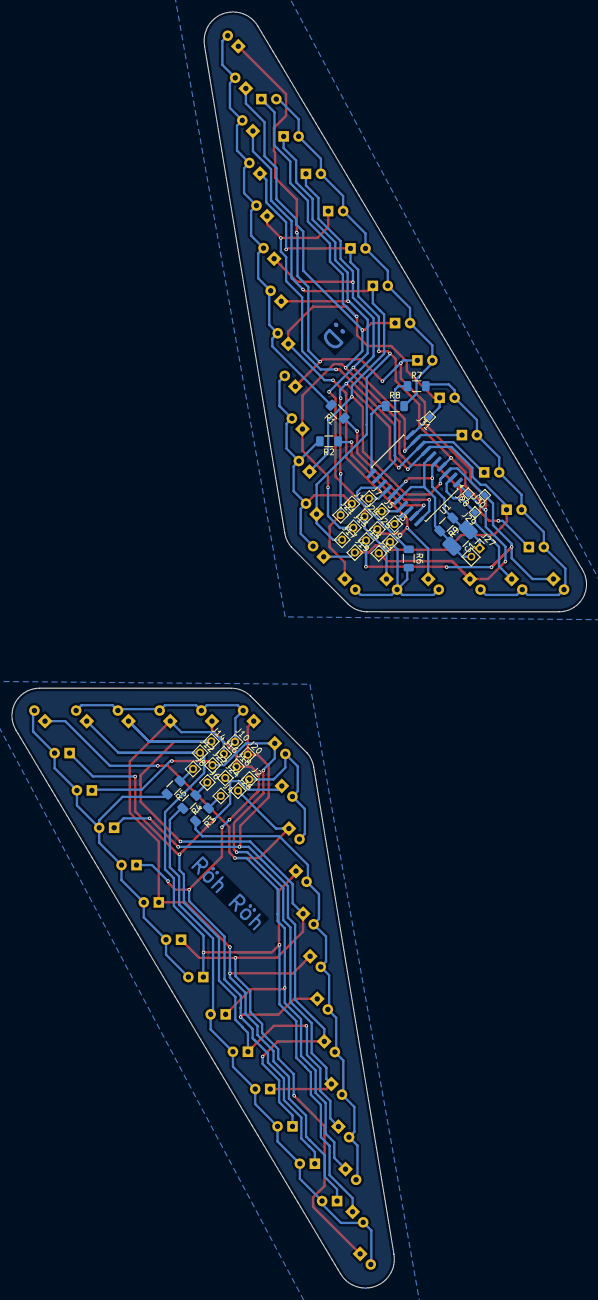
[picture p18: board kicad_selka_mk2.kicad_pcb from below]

Board: 2 copper layers, 97.4 x 216.4 mm, 106 parts (42 on the bottom side), 39 nets.

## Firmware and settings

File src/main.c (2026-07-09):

// vim: foldmethod=marker ft=c

// Teinpäs possu2 JÖÖTI version (lisäefekteillä).
// Efektien toiminta periaate sama, paitsi bufferi on 2x isompi kun 2x enemmän ledjä.
// Vaikka ISR olisi ollut ehkä parempi, tämä ei "riko" nykyistä yhteensopivuutta possu2 efektien kanssa.

// Jan Äärelä ~ 2026
// ELEKTRONIIKKAKERHO

// Tuodaan muut tiedotot.
#include "kuviot.h"
#include <avr/io.h>
#include <util/delay.h>

// Main funktio
int main(void) {

    // 16MHz PLL asetukset
    // Low fuse = E1
    // CLKPR = (1 << CLKPCE);
    // CLKPR = 0;

    // Tässäpä ne efektit looppaa.
    while (1) {

        // NOTE: Eka parametri kerrrat,
        // Toinen nopeus (montako kertaa vilkuttaa)

        // Testaus kamaa
        // onebyone(1, 20);
        // kirkkaustesti();
        // kaikki(15);

        // Looppaa muut efektit
        for (uint8_t loop = 0; loop < 31; loop++) {
            taytto(2, 1);
            himmennys(2, 7);
            kaks(2, 1);
            alas(2, 2);
            ympari(2, 2);
            kolmiotk(2, 4);
            kolari(2, 1);
            kukka2(2, 3);
        }
    }
}

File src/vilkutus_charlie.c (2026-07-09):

// vim: foldmethod=marker ft=c

// Tuodaan muut tiedostot.
#include <avr/io.h>
#include <stdint.h>
#include <util/delay_basic.h>

extern int8_t kirkkaus[64];

// "PWM" Ajoitukset {{{
const uint8_t K_VAIHEET
    [16] = { 0, 1, 2, 4, 5, 10, 15, 21, 29, 39, 51, 65, 82, 101, 122, 127 };

//  }}}

// Ledi configuraatiot {{{
// NOTE: Vasemman puoleinen anodi
// Oikea katodi

uint8_t ledi_configuraatio[32][2] = {

    // 1. Pysty rivi (SKEMA)
    { 6, 0 },
    { 0, 6 },
    { 6, 1 },
    { 1, 6 },
    { 6, 2 },
    { 2, 6 },
    { 6, 3 },
    { 3, 6 },
    { 6, 4 },
    { 4, 6 },
    { 6, 5 },
    { 5, 6 },

    // 2. ...
    { 5, 0 },
    { 0, 5 },
    { 5, 1 },
    { 1, 5 },
    { 5, 2 },
    { 2, 5 },
    { 5, 3 },
    { 3, 5 },
    { 5, 4 },
    { 4, 5 },

    // 3. ...
    { 4, 0 },
    { 0, 4 },
    { 4, 1 },
    { 1, 4 },
    { 4, 2 },
    { 2, 4 },
    { 4, 3 },
    { 3, 4 },

    // 4. ...
    { 3, 0 },
    { 0, 3 }
};

// }}}

// Ledi päälle {{{
void A_on(uint8_t ledi_1) {
    uint8_t high_pin = ledi_configuraatio[ledi_1][0];
    uint8_t low_pin = ledi_configuraatio[ledi_1][1];

    DDRA = (1 << high_pin) | (1 << low_pin);
    PORTA = (1 << high_pin);
}

void B_on(uint8_t ledi_2) {
    uint8_t high_pin = ledi_configuraatio[ledi_2][0];
    uint8_t low_pin = ledi_configuraatio[ledi_2][1];

    DDRB = (1 << high_pin) | (1 << low_pin);
    PORTB = (1 << high_pin);
}

// }}}

// Ledi pois päältä {{{

// PORT A ledit
void A_off(void) {
    PORTA = 0x00;
    DDRA = 0x00;
}

// PORT B ledit
void B_off(void) {
    PORTB = 0x00;
    DDRB = 0x00;
}
// }}}

// Ledien vikuttaminen {{{
void vilkutus(void) {
    int8_t *kirkptr1;
    int8_t *kirkptr2;
    int8_t kirk1;
    int8_t kirk2;
    uint8_t pari;
    int16_t taimeri;

    kirkptr1 = &kirkkaus[0]; // kirkkaustaulukon pointteri
    kirkptr2 = &kirkkaus[13];

    for (pari = 0; pari <= 31; pari++) {

        // Preppaus --------------------------------------------------

        // Hankitaan ledien kirkkausarvot, ettei joka kerta tarttee hakea taulukosta
        kirk1 = K_VAIHEET[*kirkptr1];
        kirk2 = K_VAIHEET[*kirkptr2];

        // Asetetaan rivit päälle saman tien...

        if (kirk1 == 1) {
            A_on(pari);
            A_off();
        }

        if (kirk1 == 2) {
            A_on(pari);
            _delay_loop_1(8);
            A_off();
        }

        if (kirk1 == 4) {
            A_on(pari);
            _delay_loop_1(16);
            A_off();
        }

        if (kirk2 == 1) {
            B_on(pari);
            B_off();
        }

        if (kirk2 == 2) {
            B_on(pari);
            _delay_loop_1(8);
            B_off();
        }

        if (kirk2 == 4) {
            B_on(pari);
            _delay_loop_1(16);
            B_off();
        }

        if (kirk1 >= 5) {
            A_on(pari);
        }

        if (kirk2 >= 5) {
            B_on(pari);
        }

        // Varsinainen ledien vilkuttaminen --------------------------

        // Härskä taimeri setuppi, mutta helposti laajentavissa
        for (taimeri = 0; taimeri <= 127; taimeri++) {

            // Laittaa nollan PORTA:han jos ledi poistuu
            if (taimeri == kirk1) {
                A_off();
            }

            if (taimeri == kirk2) {
                B_off();
            }
        }

        // Ledit pois päältä
        A_off();
        B_off();

        // Seuraavien ledien setuppiin -------------------------------

        // Siirry seuraavaan kirkkaustalukon pointteriin offsetilla
        kirkptr1++;
        kirkptr2++;

        // if (*kirkptr1 == 10) {
        //     kirkptr1 += 31;
        // }

        if ((kirkptr1 - kirkkaus) == 13) {
            kirkptr1 = &kirkkaus[45];
        }
    }
} // }}}

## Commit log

2026-02-06 Uusi leiska
    [sik_ledimössö.kicad_pcb]
2026-02-12 Ny ois eka toimiva levy
    [salama-64.kicad_pcb, salama-64.kicad_sch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]
2026-02-12 Init Next Gen Selkäsalama
    [kicad_selka_mk1.kicad_pcb, kicad_selka_mk1.kicad_sch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]
2026-02-13 Selkäsalaman skemaan lisätty jumperit
    [kicad_selka_mk1.kicad_pcb, kicad_selka_mk1.kicad_sch]
2026-02-13 Selkäsalama 90% done
    [kicad_selka_mk1.kicad_pcb]
2026-02-14 Selkäsalama 95% done
    [kicad_selka_mk1.kicad_pcb, kicad_selka_mk1.kicad_sch]
2026-02-15 Selkäsalama redo
    1 ledi meni väärälle puolelle -> 31 & 33 lediä :C
    Samahan se oli tehdä koko leiska uudelleen parammilla array
    ledipaikoilla...
    [kicad_selka_mk1.kicad_pcb, kicad_selka_mk1.kicad_sch]
2026-02-15 selkäsalama mk1 done
    [kicad_selka_mk1-B_Cu.gbr, kicad_selka_mk1-B_Mask.gbr, kicad_selka_mk1-Edge_Cuts.gbr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]
2026-02-21 selkäsalama mk1 rev 2
    [kicad_selka_mk1-B_Cu.gbl, kicad_selka_mk1-B_Cu.gbr, kicad_selka_mk1-B_Mask.gbr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]
2026-03-01 Selkäsalama toimii
    Kasattu selkäsalama ja se toimii.
    Ledien PWM ajotuksia puolittu, oli 312us eli 64 ledillä se olisi ollut
    50Hz. Nyt 156 jolloin tajuus on sen 100Hz verran.
    Korjattu muutama efekti.
    [kicad_selka_mk1-B_Cu.gbr, kicad_selka_mk1-B_Mask.gbr, kicad_selka_mk1-Edge_Cuts.gbr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]
2026-03-06 Init waunut salama
    [kicad_selka_mk1-B_Cu.gbl, kicad_selka_mk1-B_Cu.gbr, kicad_selka_mk1-B_Mask.gbr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]
2026-03-09 2 lediä vilkkuu - vilkutus_2x.c
    Jostain syystä kummallinen if statementti jossa 2 lediä palaa mutta eri
    kirrkaudella.
    Muutama ledi himmenee/kirkastuu. hmm...
    Muuten jeba
    [kicad_waunut.kicad_pcb, kicad_waunut.kicad_sch]
2026-03-11 Selkäsalaman kuoret
    blender_selka kansiosta nyt löytyy selkäsalmaan kuoret.
    blender tiedostossa itse levy ja iteraatioita kuoreja.
    V3 on hjuva ja napsahtaa mukavasti kohdalleen.
    Valmiina kuoret_v3.stl tiedosto mikä voi laittaa suoraan tulostukseen.
    Tulostuksessa käytin prusa one +, PETG ~ 15 min tulostus.
    Toleranssit tossa tulostimessa 0.2mm, joten jos on tarvetta muokata
    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
    [kuoret.blend]
2026-03-14 Selkäsalaman readme päivittelyä
    Laitoin nyt oikean kuoret stl tiedoston missä on vain 1 kuori
2026-03-16 Waunujen skemaa muutettu. README tiedostoja päivitetty.
    [kicad_waunut.kicad_pcb, kicad_waunut.kicad_sch]
2026-03-27 Kicad projekti tiedostoja siirrelty, selkä rev2 init ja waunujen skema muutosta.
    [kicad_selka_mk1.kicad_pcb, kicad_selka_mk1.kicad_sch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]
2026-04-10 Lisää putsausta ja selkäsalaman muutosta
    [kicad_selka_mk1-B_Cu.gbl, kicad_selka_mk1-B_Cu.gbr, kicad_selka_mk1-B_Mask.gbr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]
2026-06-02 hiomista vaille rev
    [kicad_selka_mk2.kicad_pcb, kicad_selka_mk2.kicad_sch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]
2026-07-09 Selkäsalama rev2 done
    Skema ja leiska valmis rev2.
    Tilattu R2-260625. Toimii ja näyttää hjuvalta.
    Siirtin kamaa /archive kansioon. mm. vanhat ja proto versiot.
    Vanhat media tiedostot jne.
    [kicad_selka_mk1-B_Cu.gbl, kicad_selka_mk1-B_Cu.gbr, kicad_selka_mk1-B_Mask.gbr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]
2026-07-09 Putsausta
    Poistin vanhoja bk kansioita.
    Putsasin koodia.
    a
    [kicad_selka_mk1-B_Cu.gbl, kicad_selka_mk1-B_Cu.gbr, kicad_selka_mk1-B_Mask.gbr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]
